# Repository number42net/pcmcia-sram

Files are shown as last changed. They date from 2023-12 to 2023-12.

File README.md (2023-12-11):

# PCMCIA SRAM board

This board is primarily designed for use in the Amstrad NC-100 and NC-200 portable computers, but will likely work in other computers as well.

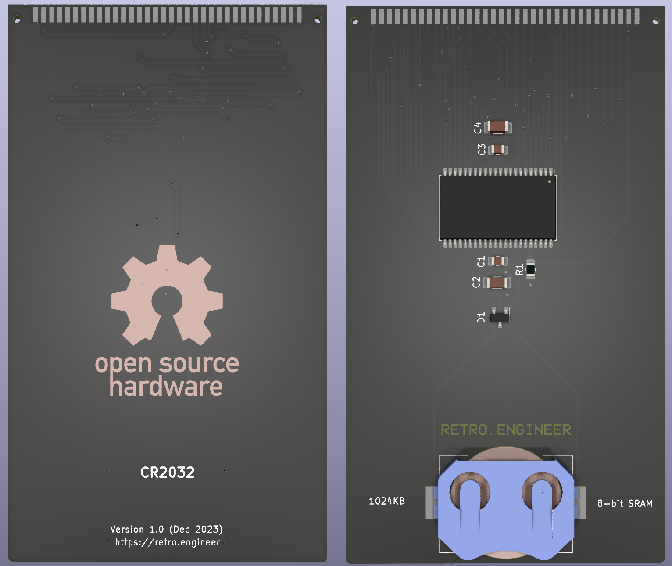
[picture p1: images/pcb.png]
PCB


## Specifications:
+ 1024K * 8 bits static RAM
+ CR2032 backup battery
+ Long battery life expected, but not yet tested

## Potential issues
+ This project has not yet been fully tested! **Build it at your own risk!**
+ Will likely not work in computers that expect a 16bit card, but this hasn't been tested
+ Currently no write protect switch

## Design
+ This product is Open Source, licensed under [CERN-OHL-P v2](https://ohwr.org/cern_ohl_p_v2.txt)
+ The schematics and PCB designs have been produced with KiCAD 6.0

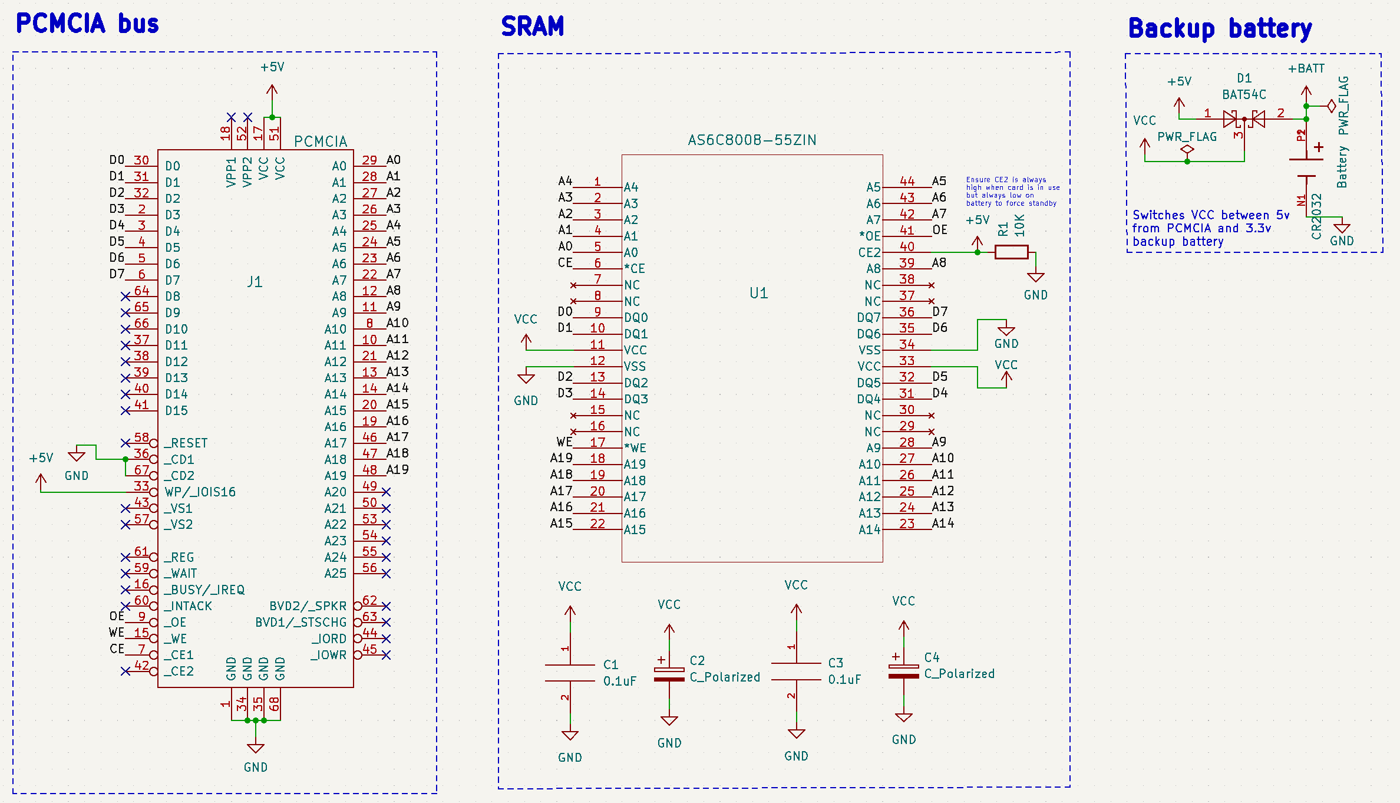
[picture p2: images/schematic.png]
schematic


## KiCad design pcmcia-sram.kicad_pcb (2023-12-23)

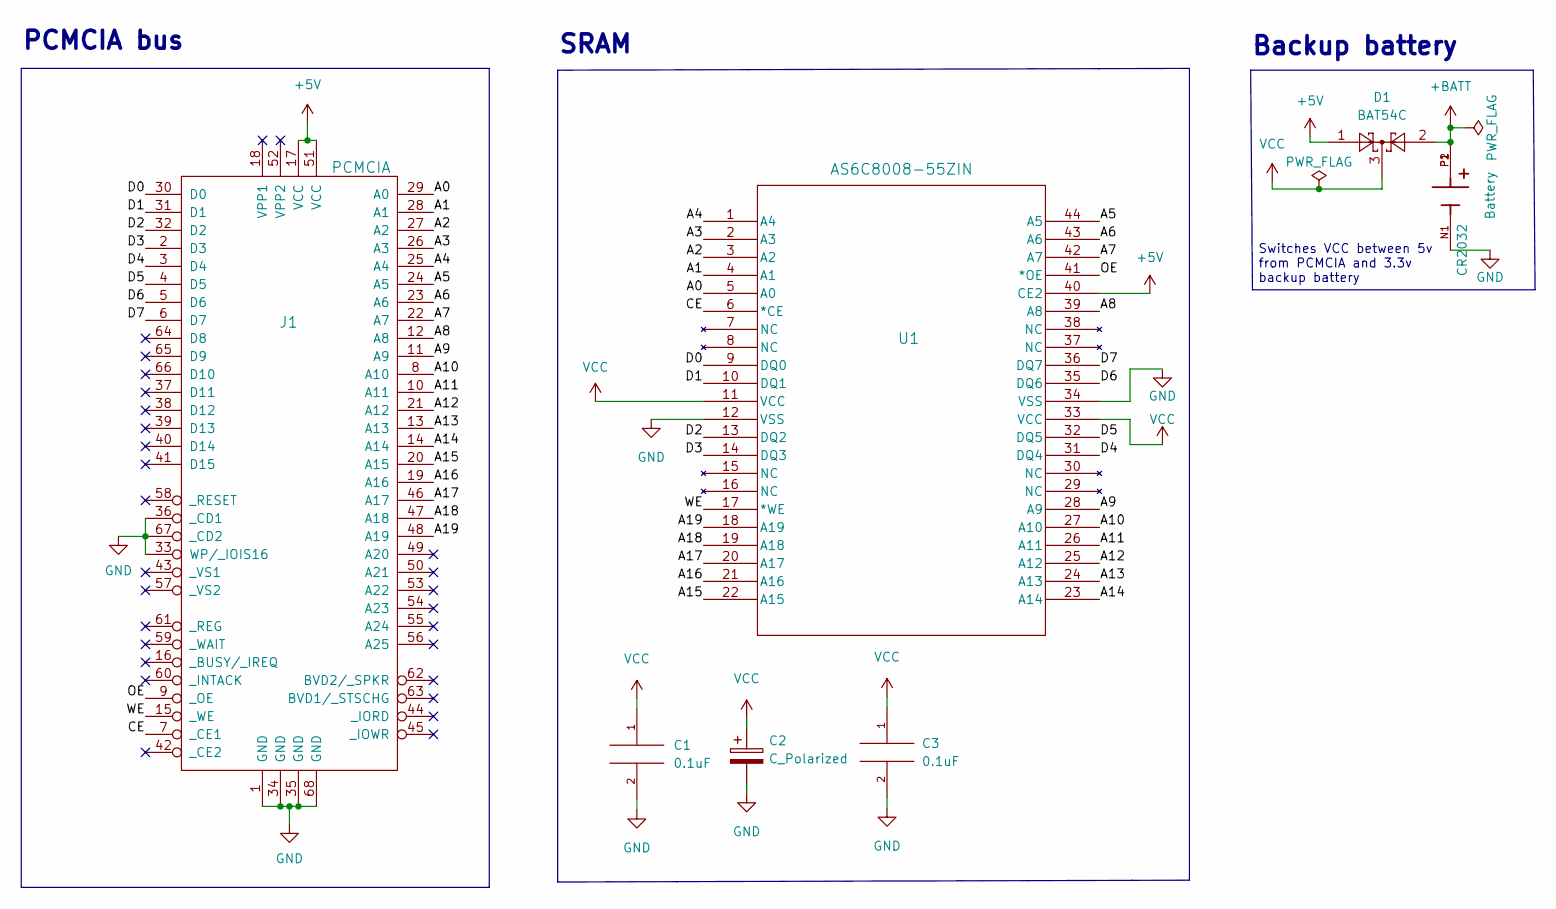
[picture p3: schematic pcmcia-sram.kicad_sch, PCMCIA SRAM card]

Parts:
C1, C3: 0.1uF; C_0805_2012Metric_Pad1.18x1.45mm_HandSolder
C2: C_Polarized; C_1206_3216Metric_Pad1.33x1.80mm_HandSolder
CR2032: Battery; BAT_BAT-HLD-001
D1: BAT54C; SOT-23
J1: PCMCIA; pcmcia
U1: AS6C8008-55ZIN; TSOP-II-44_10.16x18.41mm_P0.8mm

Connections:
+5V: D1.1, J1.17 (VCC), J1.51 (VCC), U1.40 (CE2)
+BATT: CR2032.P1, CR2032.P2, D1.2
/A0: J1.29 (A0), U1.5 (A0)
/A1: J1.28 (A1), U1.4 (A1)
/A2: J1.27 (A2), U1.3 (A2)
/A3: J1.26 (A3), U1.2 (A3)
/A4: J1.25 (A4), U1.1 (A4)
/A5: J1.24 (A5), U1.44 (A5)
/A6: J1.23 (A6), U1.43 (A6)
/A7: J1.22 (A7), U1.42 (A7)
/A8: J1.12 (A8), U1.39 (A8)
/A9: J1.11 (A9), U1.28 (A9)
/A10: J1.8 (A10), U1.27 (A10)
/A11: J1.10 (A11), U1.26 (A11)
/A12: J1.21 (A12), U1.25 (A12)
/A13: J1.13 (A13), U1.24 (A13)
/A14: J1.14 (A14), U1.23 (A14)
/A15: J1.20 (A15), U1.22 (A15)
/A16: J1.19 (A16), U1.21 (A16)
/A17: J1.46 (A17), U1.20 (A17)
/A18: J1.47 (A18), U1.19 (A18)
/A19: J1.48 (A19), U1.18 (A19)
/CE: J1.7 (_CE1), U1.6 (*CE)
/D0: J1.30 (D0), U1.9 (DQ0)
/D1: J1.31 (D1), U1.10 (DQ1)
/D2: J1.32 (D2), U1.13 (DQ2)
/D3: J1.2 (D3), U1.14 (DQ3)
/D4: J1.3 (D4), U1.31 (DQ4)
/D5: J1.4 (D5), U1.32 (DQ5)
/D6: J1.5 (D6), U1.35 (DQ6)
/D7: J1.6 (D7), U1.36 (DQ7)
/OE: J1.9 (_OE), U1.41 (*OE)
/WE: J1.15 (_WE), U1.17 (*WE)
GND: C1.2, C2.2, C3.2, CR2032.N1, J1.1 (GND), J1.33 (WP/_IOIS16), J1.34 (GND), J1.35 (GND), J1.36 (_CD1), J1.67 (_CD2), J1.68 (GND), U1.12 (VSS), U1.34 (VSS)
VCC: C1.1, C2.1, C3.1, D1.3, U1.11 (VCC), U1.33 (VCC)

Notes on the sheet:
Backup battery
Switches VCC between 5v from PCMCIA and 3.3v backup battery
PCMCIA bus
SRAM

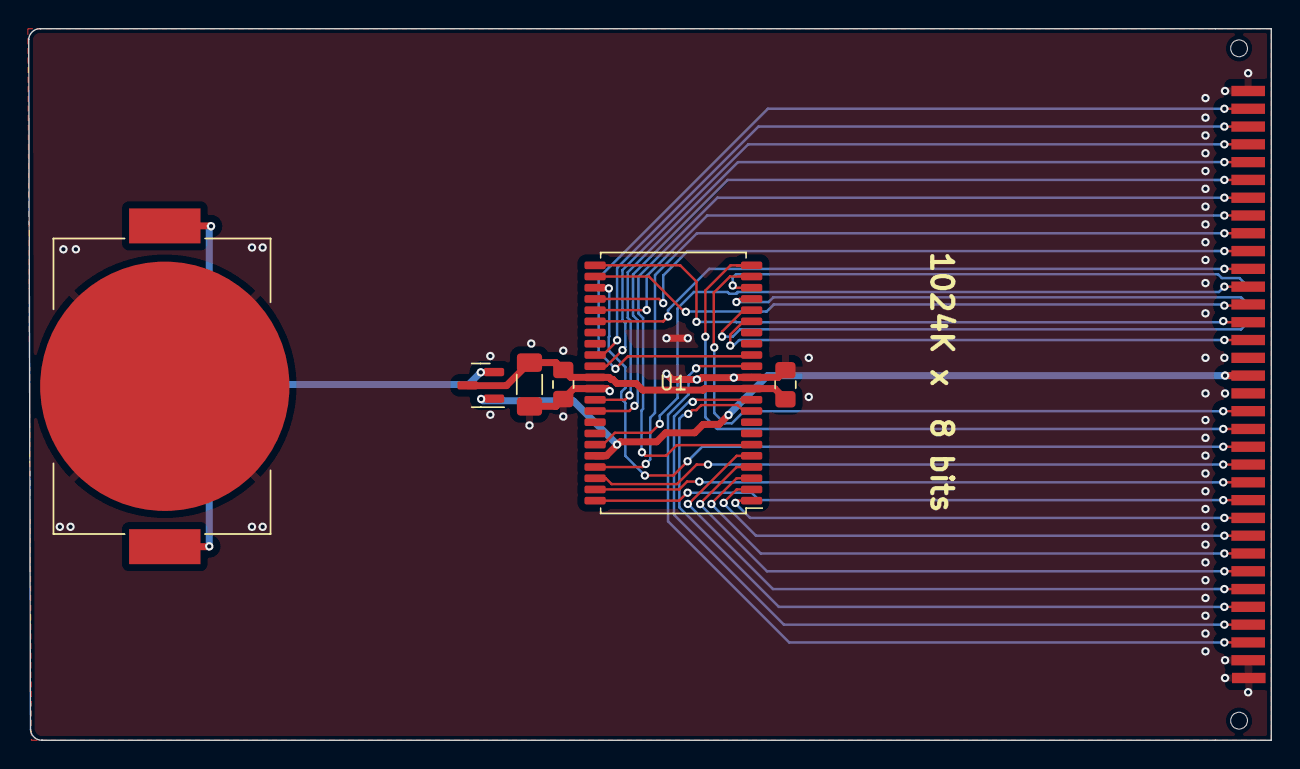
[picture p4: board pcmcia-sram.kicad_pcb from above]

Board: 2 copper layers, 88.7 x 50.8 mm, 7 parts (0 on the bottom side), 35 nets.

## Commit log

2023-12-10 Copy of pcmcia-breakout
    [pcmcia-sram.kicad_pcb, pcmcia-sram.kicad_sch]
2023-12-10 Schematic done
    [pcmcia-sram.kicad_sch]
2023-12-10 Initial layout
    [pcmcia-sram.kicad_pcb]
2023-12-10 Fixed address pin
    [pcmcia-sram.kicad_sch]
2023-12-10 Various fixes
    [pcmcia-sram.kicad_pcb, pcmcia-sram.kicad_sch]
2023-12-11 Add KiCad version
2023-12-23 Add new design
    [pcmcia-sram copy.kicad_pcb, pcmcia-sram.kicad_sch]
2023-12-23 Revision 1.1
    [pcmcia-sram copy.kicad_pcb, pcmcia-sram.kicad_pcb, pcmcia-sram.kicad_sch]
